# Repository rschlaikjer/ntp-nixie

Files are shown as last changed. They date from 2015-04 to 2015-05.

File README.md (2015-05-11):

# Nixie-NTP

### Nixie clock with NTP synchronisation

Like every amateur electrical engineer, I felt the need to make my own nixie
clock. However, I decided to add a bit of modern day tech and have the clock
set itself over NTP instead of requiring the user to manually adjust buttons.

The schematics provided detail the two boards - one control (arduino, ethernet)
and one display (shift registers, high voltage transistors).

## Partlist
#### (Digikey P/N in parens)

**Logic:**

- Atmega 328P (ATMEGA328-PU-ND / $3.01)
- Silvertel A9700 PoE module (N/A / $10)
- ENC28J60 ethernet PHY (ENC28J60-I/SO-ND / $2.83)
- RB1-125BHQ1A RJ45 jack with magnetics (N/A / $3.00)
- LM1117 3.3V regulator (LM1117T-3.3/NOPB-ND / $1.49)

**12-200V DC Boost:**
- 0.1uF 250V film cap (PCF1412CT-ND / $2.25)
- 4.7uF 450V alum cap (493-6196-1-ND / $1.51)
- MAX1771 DC-DC switching controller (MAX1771EPA+-ND / $7.23)
- 250V MOSFET (IRF644PBF-ND / $1.23)
- 100uF 20V tantalum cap (478-1746-1-ND / $2.52)
- 0.1uF 25V ceramic cap (490-1726-1-ND / $0.05)
- 10uF 25V tantalum cap (478-1762-1-ND / $1.02)
- 300V diode (ES2F-E3/52TGICT-ND / $0.40)
- 10k resistor (311-10.0KCRCT-ND / $0.02)
- 100uH inductor (M8603CT-ND / $0.81)
- 1.5M resistor (PT1.5MXCT-ND / $0.80)
- 0.05 ohm resistor (P50MCT-ND / $1.14)
- 5k trimmer pot (3214W-502ECT-ND / $3.18)

**Display Board**

- LS595 shift register with latch (296-1600-5-ND, $0.62)
- MPSA42 (or similar) high voltage transistors (MPSA42FS-ND, $0.22)
- Nixie tubes (Eagle footprint designed around the IN-14, YMMV)
- 1k resistors for regulating transistor base current
- 15k resistors for limiting nixie current

## Pretty pictures

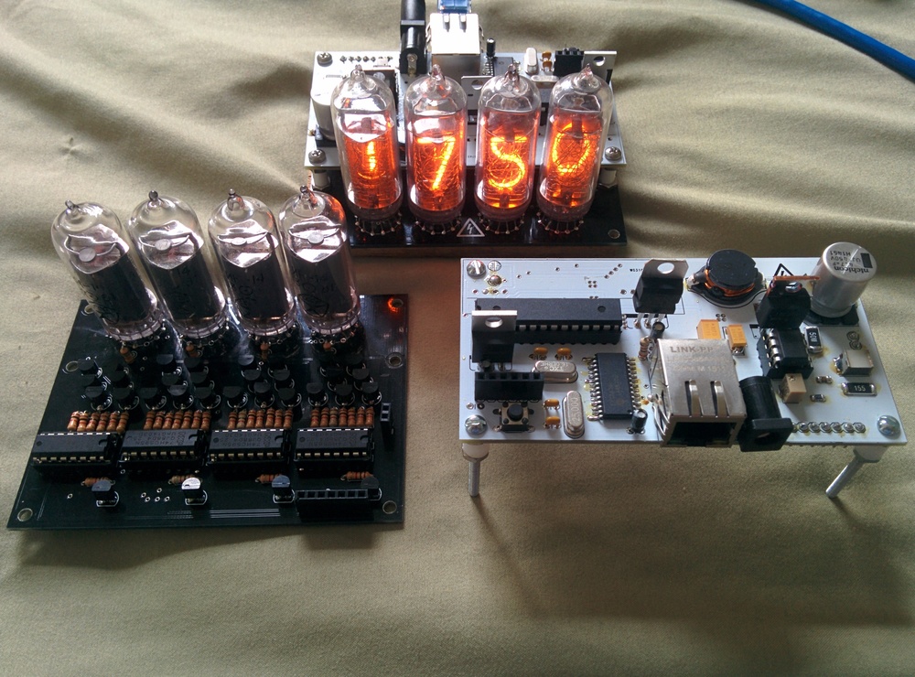
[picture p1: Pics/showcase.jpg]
Pretty It's alive

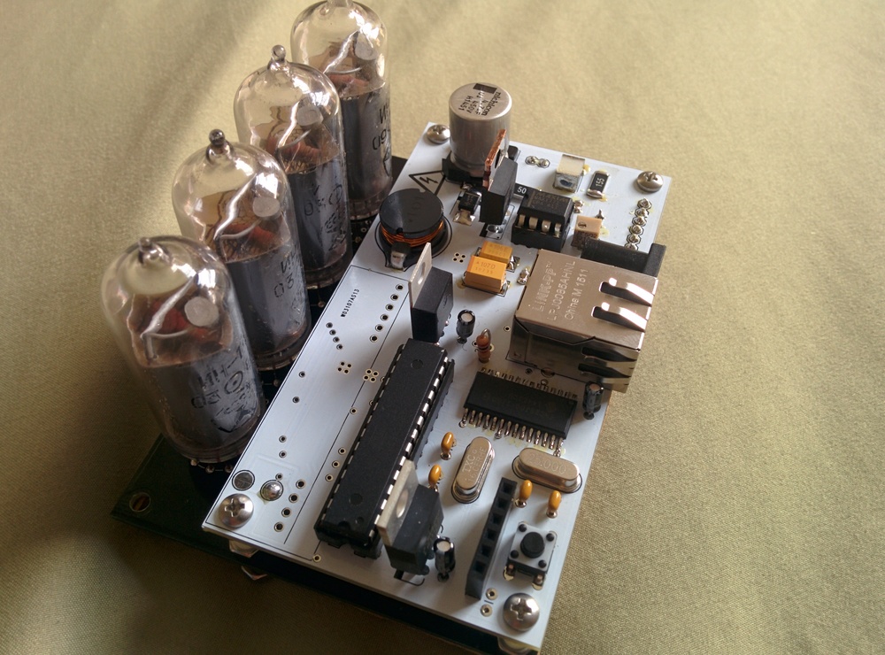
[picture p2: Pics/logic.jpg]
Logic Forward display

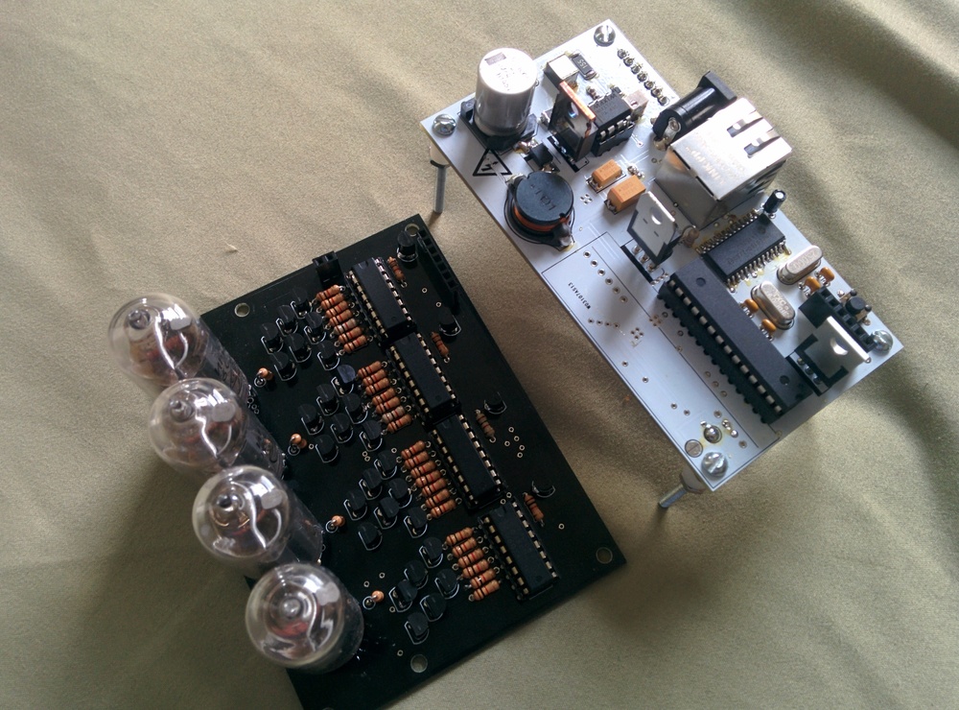
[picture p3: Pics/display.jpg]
Display Logic Display logic


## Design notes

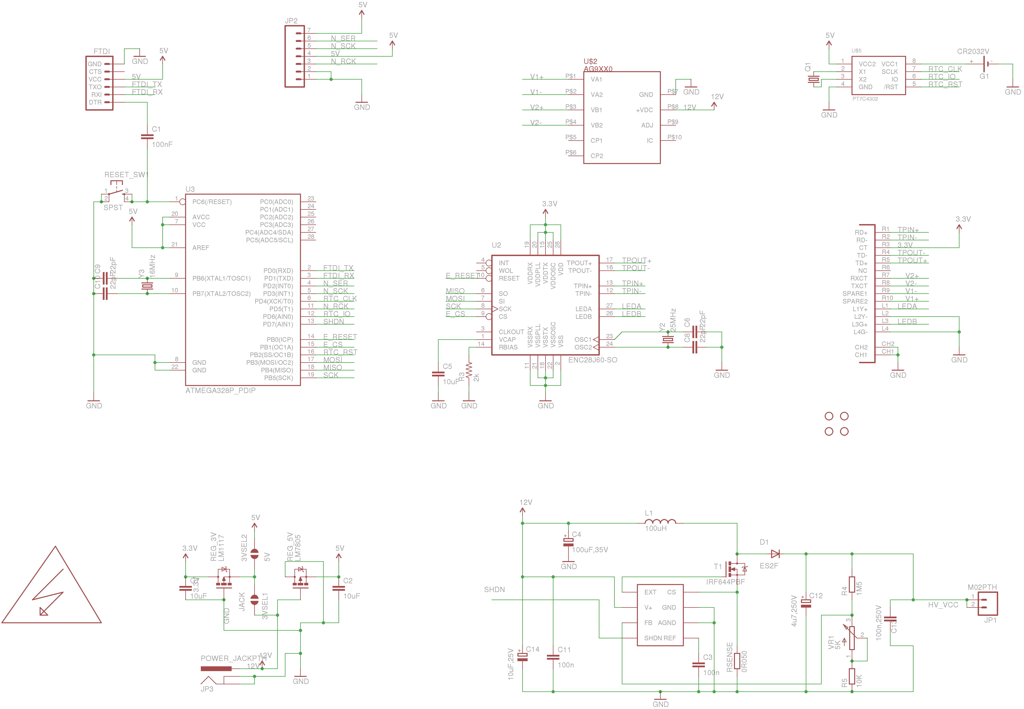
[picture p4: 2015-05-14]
Schematics/logic_schematic.png

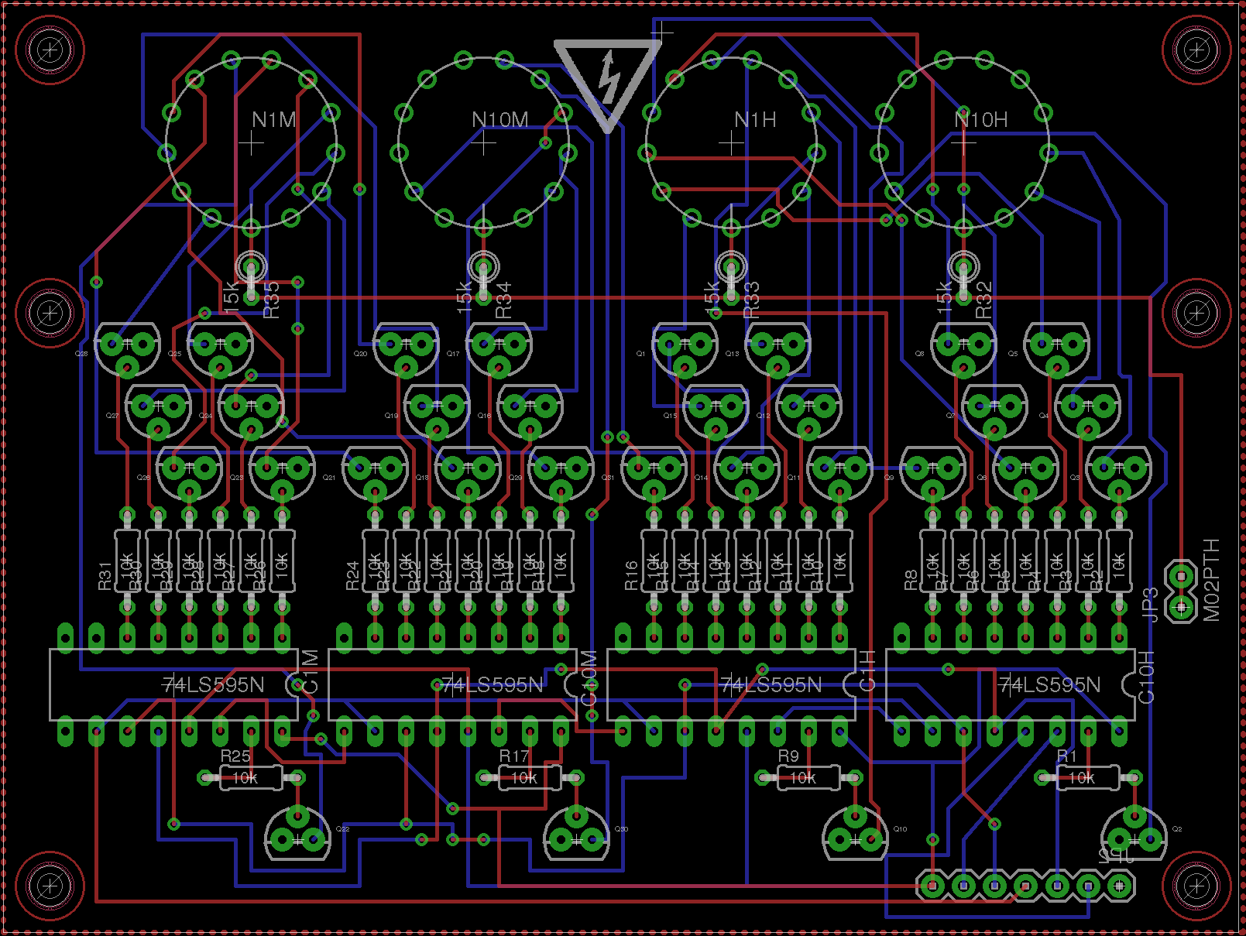
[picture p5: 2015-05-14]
Schematics/display_board.png

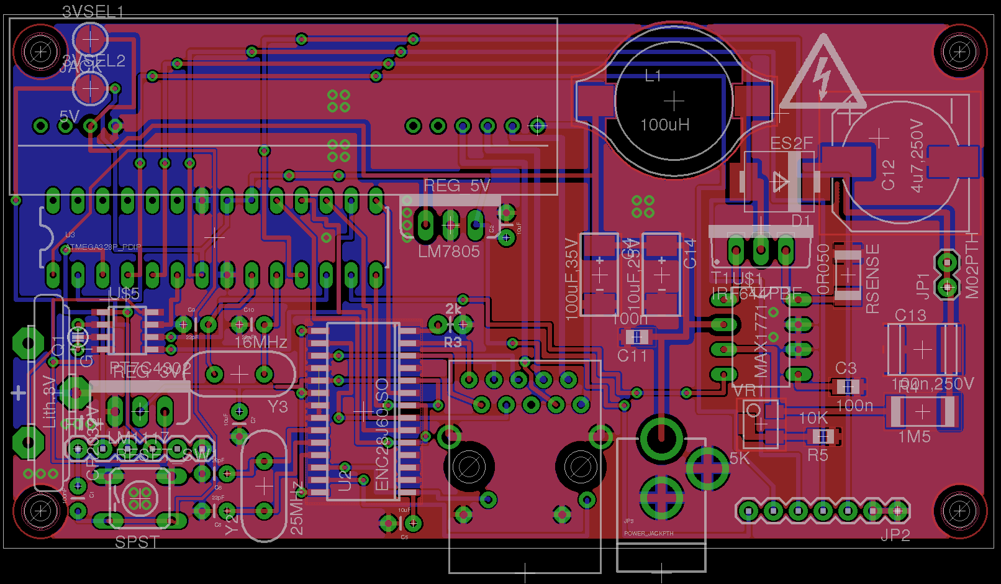
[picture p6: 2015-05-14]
Schematics/logic_board.png

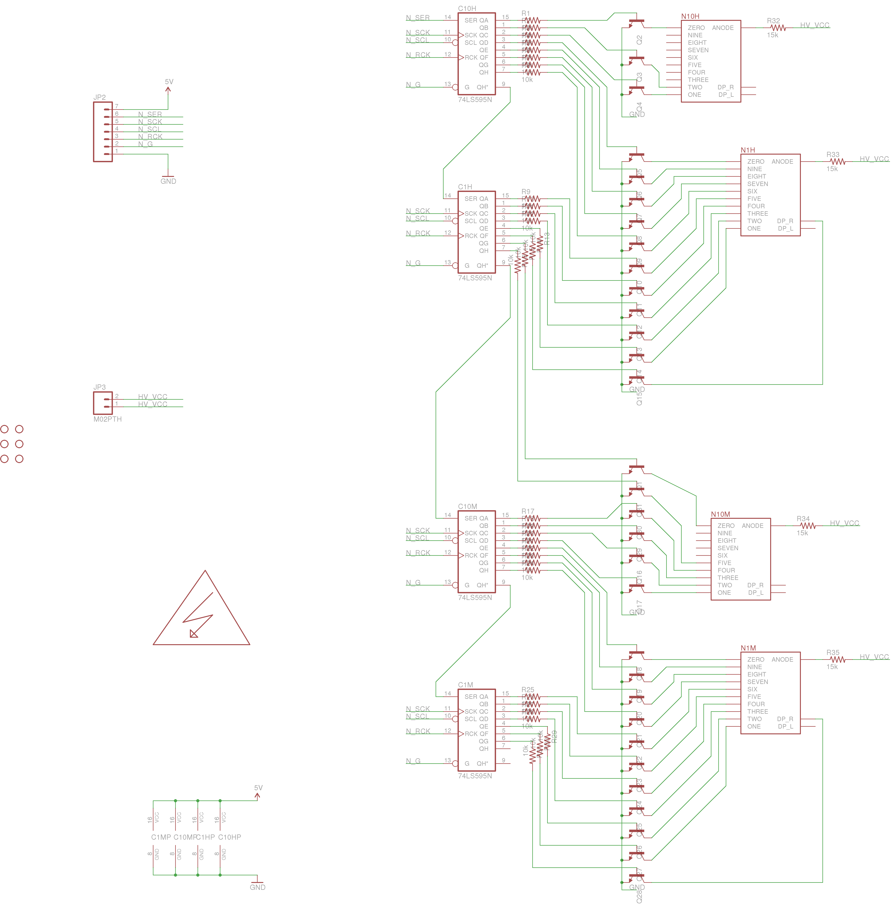
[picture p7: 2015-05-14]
Schematics/display_schematic.png

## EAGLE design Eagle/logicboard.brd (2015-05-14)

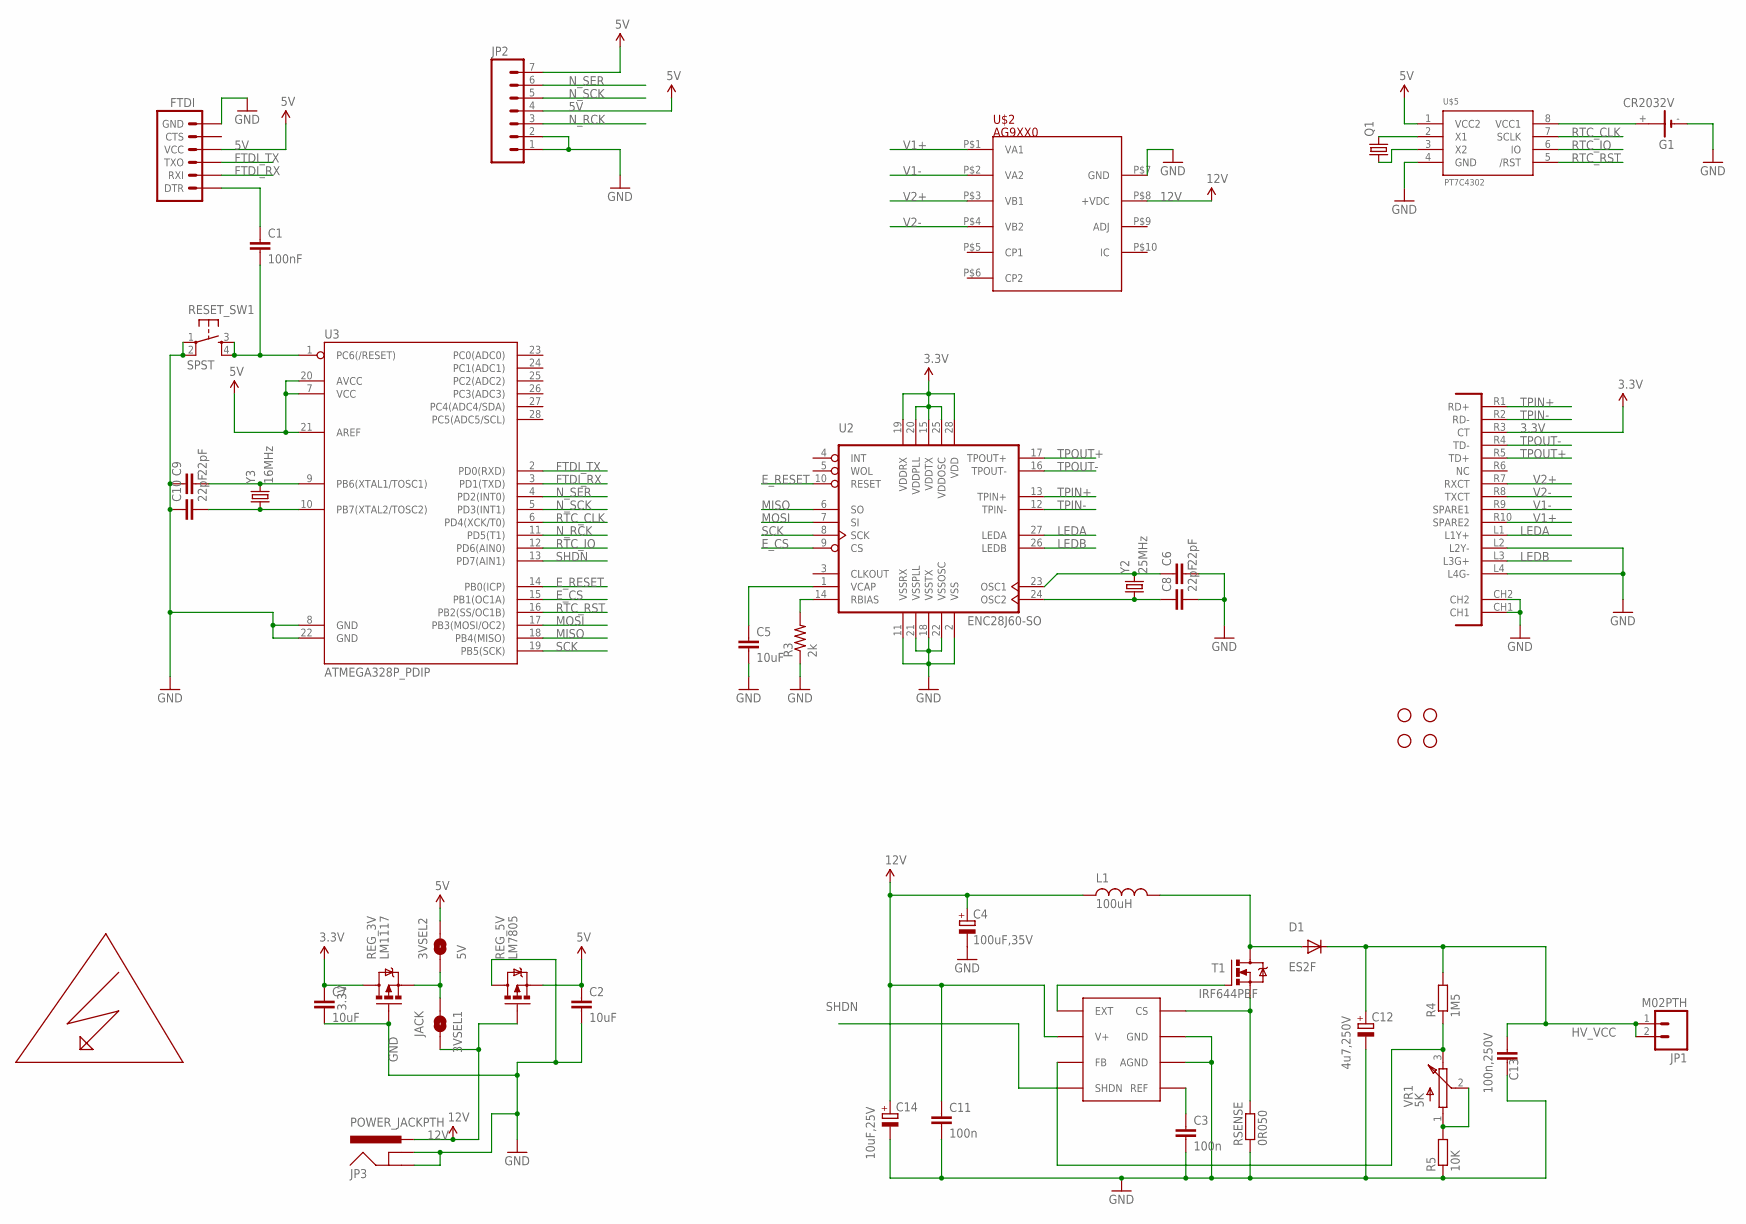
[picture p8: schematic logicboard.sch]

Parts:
3VSEL1: JACK; PAD-JUMPER-2-NO_YES_SILK_ROUND
3VSEL2: 5V; PAD-JUMPER-2-NO_YES_SILK_ROUND
C1: 100nF; CAP-PTH-SMALL
C2, C5, C7: 10uF; CAP-PTH-SMALL
C3, C11: 100n; C0805
C4: 100uF,35V; C-EIA-7343
C6, C8, C9, C10: 22pF; CAP-PTH-SMALL
C12: 4u7,250V; NICHICON-UJ-12
C13: 100n,250V; C2420
C14: 10uF,25V; C-EIA-7343
D1: ES2F; SMC
FTDI: ARDUINO_SERIAL_PROGRAMPTH; 1X06
G1: CR2032V
JP1: M02PTH; 1X02
JP2: M07; 1X07
JP3: POWER_JACKPTH; POWER_JACK_PTH
L1: 100uH; L-B82479
Q1: CRYSTALTC26V; TC26V
R3: 2k; AXIAL-0.1
R4: 1M5; R2512
R5: 10K; R0805
REG_3V: LM1117; TO220V
REG_5V: LM7805; TO220V
RESET_SW1: SPST; TAC-SWITCH-PTH
RSENSE: 0R050; R2010
STANDOFF1, STANDOFF2, STANDOFF3, STANDOFF4: STAND-OFF
T1: IRF644PBF; TO220BV
U2: ENC28J60-SO; SO28W
U3: ATMEGA328P_PDIP; DIL28-3
U$1: MAX1771; 8-DIP
U$2: AG9XX0; AG9000
U$3: POE-RJ45
U$4: HIGHVOLTAGE
U$5: PT7C4302; SO8
VR1: 5K; BOURNS-3214W
Y2: 25MHz; HC49US
Y3: 16MHz; HC49US

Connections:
3.3V: C7.1, REG_3V.2 (D), U2.15 (VDDTX), U2.19 (VDDRX), U2.20 (VDDPLL), U2.25 (VDDOSC), U2.28 (VDD), U$3.R3 (CT)
5V: 3VSEL2.2, C2.1, FTDI.4 (VCC), JP2.4, JP2.7, REG_5V.3 (S), U3.7 (VCC), U3.20 (AVCC), U3.21 (AREF), U$5.1 (VCC2)
12V: 3VSEL1.2, C4.+, C11.1, C14.+, JP3.PWR, L1.P$1 (1), REG_5V.1 (G), U$1.V+, U$2.P$8 (+VDC)
EXT: T1.G, U$1.EXT
E_CS: U2.9 (CS), U3.15 (PB1(OC1A))
E_RESET: U2.10 (RESET), U3.14 (PB0(ICP))
FTDI_RX: FTDI.2 (RXI), U3.3 (PD1(TXD))
FTDI_TX: FTDI.3 (TXO), U3.2 (PD0(RXD))
GND: C2.2, C3.2, C4.-, C5.2, C6.2, C7.2, C8.2, C9.1, C10.1, C11.2, C12.1 (-), C13.P$2 (2), C14.-, FTDI.6 (GND), G1.-, JP2.1, JP2.2, JP3.GND, JP3.GNDBREAK, R3.P$1 (1), R5.1, REG_3V.1 (G), REG_5V.2 (D), RESET_SW1.1, RESET_SW1.2, RSENSE.1, U2.2 (VSS), U2.11 (VSSRX), U2.18 (VSSTX), U2.21 (VSSPLL), U2.22 (VSSOSC), U3.8 (GND), U3.22 (GND), U$1.AGND, U$1.GND, U$2.P$7 (GND), U$3.CH1, U$3.CH2, U$3.L2 (L2Y-), U$3.L4 (L4G-), U$5.4 (GND)
HV_VCC: C12.2 (+), C13.P$1 (1), D1.C, JP1.1, JP1.2, R4.2
LEDA: U2.27 (LEDA), U$3.L1 (L1Y+)
LEDB: U2.26 (LEDB), U$3.L3 (L3G+)
MISO: U2.6 (SO), U3.18 (PB4(MISO))
MOSI: U2.7 (SI), U3.17 (PB3(MOSI/OC2))
unnamed: 3VSEL1.1, 3VSEL2.1, REG_3V.3 (S)
unnamed: G1.+, U$5.8 (VCC1)
unnamed: R3.P$2 (2), U2.14 (RBIAS)
unnamed: C5.1, U2.1 (VCAP)
unnamed: C6.1, U2.23 (OSC1), Y2.2
unnamed: C8.1, U2.24 (OSC2), Y2.1
unnamed: R5.2, VR1.1 (A), VR1.2 (W)
unnamed: R4.1, U$1.FB, VR1.3 (B)
unnamed: RSENSE.2, T1.S, U$1.CS
unnamed: C3.1, U$1.REF
unnamed: Q1.2, U$5.2 (X1)
unnamed: Q1.1, U$5.3 (X2)
unnamed: D1.A, L1.P$2 (2), T1.D
unnamed: C9.2, U3.9 (PB6(XTAL1/TOSC1)), Y3.2
unnamed: C10.2, U3.10 (PB7(XTAL2/TOSC2)), Y3.1
unnamed: C1.1, FTDI.1 (DTR)
N_RCK: JP2.3, U3.11 (PD5(T1))
N_SCK: JP2.5, U3.5 (PD3(INT1))
N_SER: JP2.6, U3.4 (PD2(INT0))
RESET: C1.2, RESET_SW1.3, RESET_SW1.4, U3.1 (PC6(/RESET))
RTC_CLK: U3.6 (PD4(XCK/T0)), U$5.7 (SCLK)
RTC_IO: U3.12 (PD6(AIN0)), U$5.6 (IO)
RTC_RST: U3.16 (PB2(SS/OC1B)), U$5.5 (/RST)
SCK: U2.8 (SCK), U3.19 (PB5(SCK))
SHDN: U3.13 (PD7(AIN1)), U$1.SHDN
TPIN+: U2.13 (TPIN+), U$3.R1 (RD+)
TPIN-: U2.12 (TPIN-), U$3.R2 (RD-)
TPOUT+: U2.17 (TPOUT+), U$3.R5 (TD+)
TPOUT-: U2.16 (TPOUT-), U$3.R4 (TD-)
V1+: U$2.P$1 (VA1), U$3.R10 (SPARE2)
V1-: U$2.P$2 (VA2), U$3.R9 (SPARE1)
V2+: U$2.P$3 (VB1), U$3.R7 (RXCT)
V2-: U$2.P$4 (VB2), U$3.R8 (TXCT)

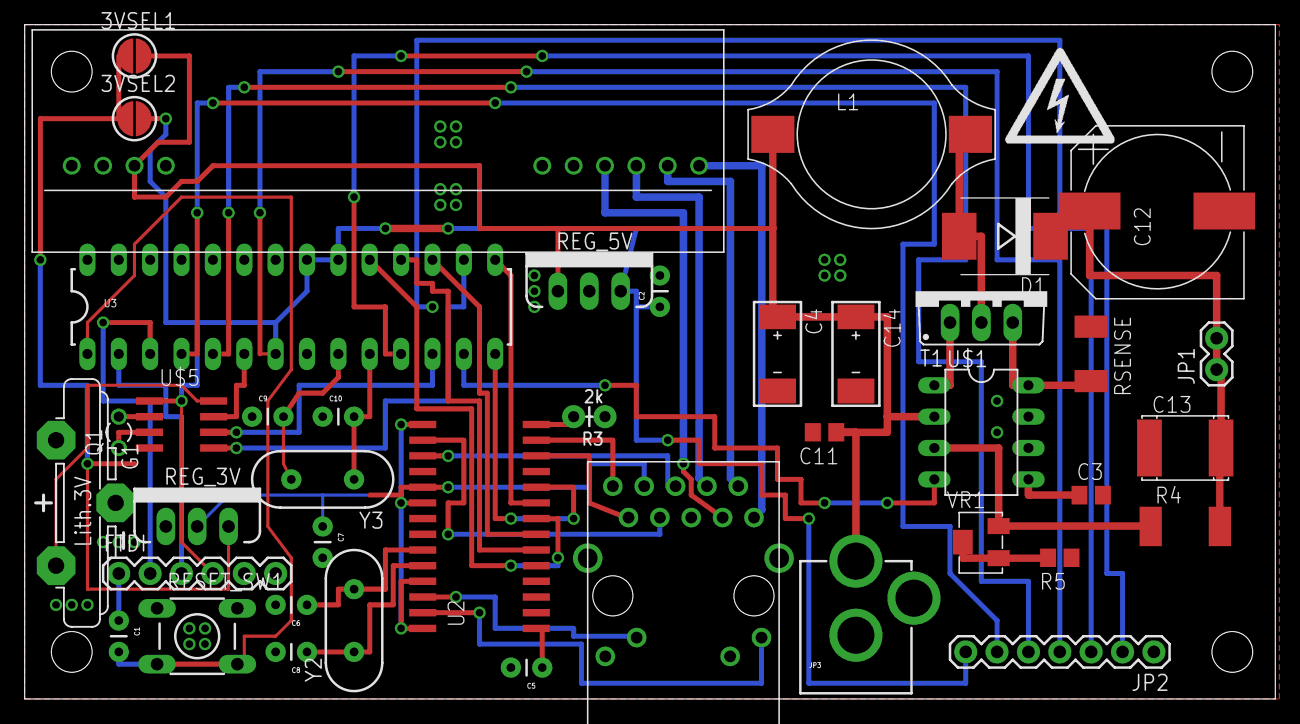
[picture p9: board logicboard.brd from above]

Board: 2 copper layers, 101.3 x 54.6 mm, 46 parts (0 on the bottom side), 47 nets.

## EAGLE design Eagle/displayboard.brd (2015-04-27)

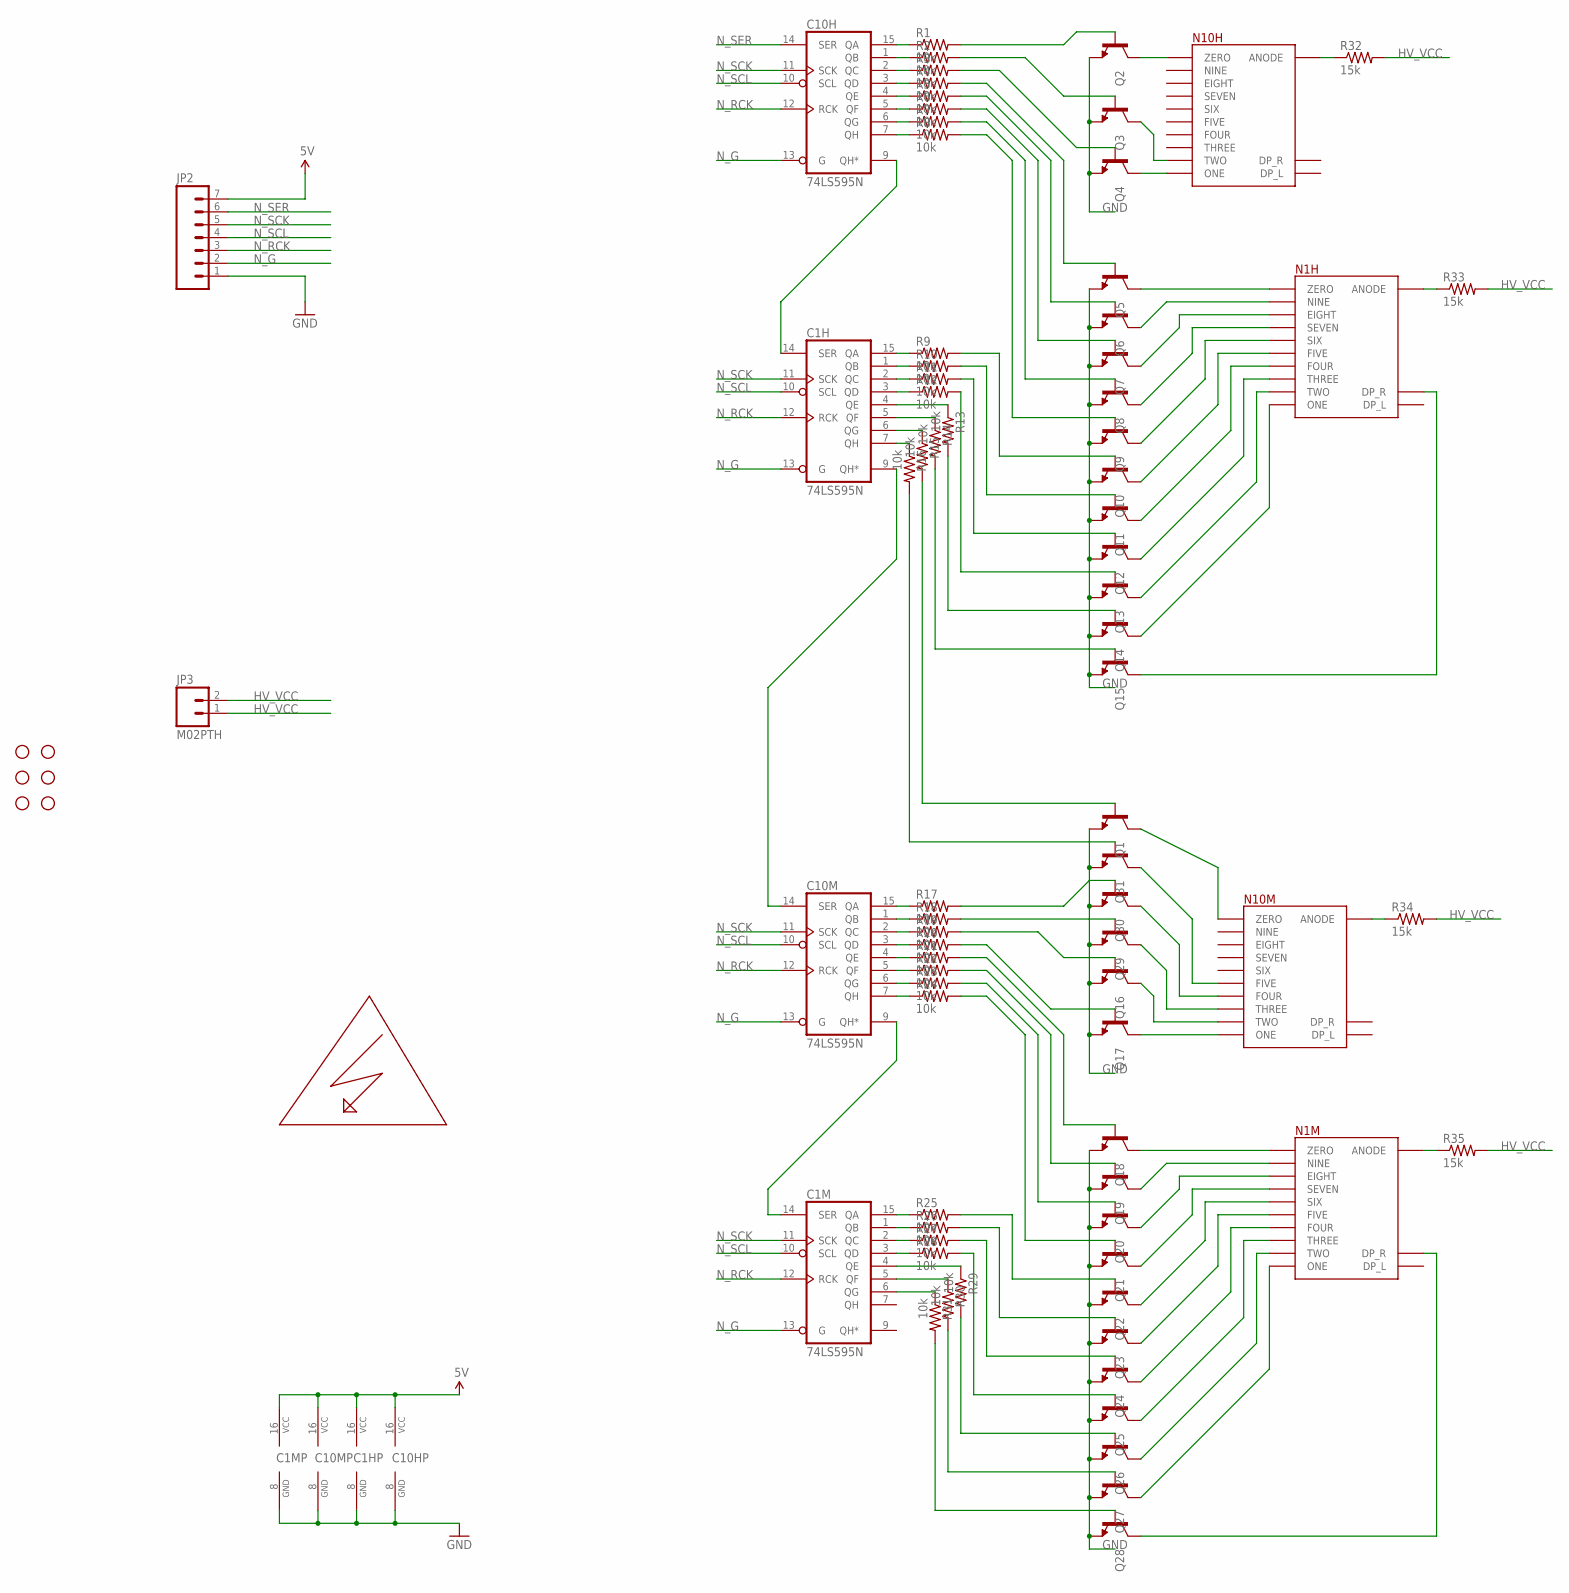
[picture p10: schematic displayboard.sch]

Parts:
C1H, C1M, C10H, C10M: 74LS595N; DIL16
JP2: M07; 1X07
JP3: M02PTH; 1X02
N1H, N1M, N10H, N10M: NIX13
Q1, Q2, Q3, Q4, Q5, Q6, Q7, Q8, Q9, Q10, Q11, Q12, Q13, Q14, Q15, Q16, Q17, Q18, Q19, Q20, Q21, Q22, Q23, Q24, Q25, Q26, Q27, Q28, Q29, Q30, Q31: TRANSISTOR_NPNTO92; TO-92
R1, R2, R3, R4, R5, R6, R7, R8, R9, R10, R11, R12, R13, R14, R15, R16, R17, R18, R19, R20, R21, R22, R23, R24, R25, R26, R27, R28, R29, R30, R31: 10k; 0204/7
R32, R33, R34, R35: 15k; 0207/2V
STANDOFF1, STANDOFF2, STANDOFF3, STANDOFF4, STANDOFF5, STANDOFF6: STAND-OFF
U$1: HIGHVOLTAGE

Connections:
5V: C1H.16 (VCC), C1M.16 (VCC), C10H.16 (VCC), C10M.16 (VCC), JP2.7
GND: C1H.8 (GND), C1M.8 (GND), C10H.8 (GND), C10M.8 (GND), JP2.1, Q1.1 (E), Q2.1 (E), Q3.1 (E), Q4.1 (E), Q5.1 (E), Q6.1 (E), Q7.1 (E), Q8.1 (E), Q9.1 (E), Q10.1 (E), Q11.1 (E), Q12.1 (E), Q13.1 (E), Q14.1 (E), Q15.1 (E), Q16.1 (E), Q17.1 (E), Q18.1 (E), Q19.1 (E), Q20.1 (E), Q21.1 (E), Q22.1 (E), Q23.1 (E), Q24.1 (E), Q25.1 (E), Q26.1 (E), Q27.1 (E), Q28.1 (E), Q29.1 (E), Q30.1 (E), Q31.1 (E)
HV_VCC: JP3.1, JP3.2, R32.2, R33.2, R34.2, R35.2
unnamed: N10H.ONE, Q4.3 (C)
unnamed: C10H.15 (QA), R1.1
unnamed: N10H.TWO, Q3.3 (C)
unnamed: N10H.ZERO, Q2.3 (C)
unnamed: N10M.THREE, Q29.3 (C)
unnamed: N1H.ONE, Q14.3 (C)
unnamed: N1H.TWO, Q13.3 (C)
unnamed: N1H.THREE, Q12.3 (C)
unnamed: N1H.FOUR, Q11.3 (C)
unnamed: N1H.FIVE, Q10.3 (C)
unnamed: N1H.SIX, Q9.3 (C)
unnamed: N1H.SEVEN, Q8.3 (C)
unnamed: N1H.EIGHT, Q7.3 (C)
unnamed: N1H.NINE, Q6.3 (C)
unnamed: N1H.ZERO, Q5.3 (C)
unnamed: N10M.FOUR, Q30.3 (C)
unnamed: N1H.DP_R, Q15.3 (C)
unnamed: Q2.2 (B), R1.2
unnamed: Q3.2 (B), R2.2
unnamed: C10H.1 (QB), R2.1
unnamed: C10H.2 (QC), R3.1
unnamed: Q4.2 (B), R3.2
unnamed: Q5.2 (B), R4.2
unnamed: Q6.2 (B), R5.2
unnamed: Q7.2 (B), R6.2
unnamed: Q8.2 (B), R7.2
unnamed: Q9.2 (B), R8.2
unnamed: Q10.2 (B), R9.2
unnamed: Q11.2 (B), R10.2
unnamed: Q12.2 (B), R11.2
unnamed: Q13.2 (B), R12.2
unnamed: Q14.2 (B), R13.2
unnamed: Q15.2 (B), R14.2
unnamed: N10M.ONE, Q17.3 (C)
unnamed: N10M.FIVE, Q31.3 (C)
unnamed: Q1.2 (B), R15.2
unnamed: N1M.ONE, Q27.3 (C)
unnamed: N1M.TWO, Q26.3 (C)
unnamed: N1M.THREE, Q25.3 (C)
unnamed: N1M.FOUR, Q24.3 (C)
unnamed: N1M.FIVE, Q23.3 (C)
unnamed: N1M.SIX, Q22.3 (C)
unnamed: N1M.SEVEN, Q21.3 (C)
unnamed: N1M.EIGHT, Q20.3 (C)
unnamed: N1M.NINE, Q19.3 (C)
unnamed: N1M.ZERO, Q18.3 (C)
unnamed: N10M.TWO, Q16.3 (C)
unnamed: N10M.ZERO, Q1.3 (C)
unnamed: N1M.DP_R, Q28.3 (C)
unnamed: Q30.2 (B), R17.2
unnamed: C10M.15 (QA), R17.1
unnamed: Q29.2 (B), R18.2
unnamed: C10H.3 (QD), R4.1
unnamed: C10H.4 (QE), R5.1
unnamed: C10H.5 (QF), R6.1
unnamed: C10H.6 (QG), R7.1
unnamed: Q22.2 (B), R25.2
unnamed: Q23.2 (B), R26.2
unnamed: Q24.2 (B), R27.2
unnamed: Q25.2 (B), R28.2
unnamed: Q26.2 (B), R29.2
unnamed: Q27.2 (B), R30.2
unnamed: Q28.2 (B), R31.2
unnamed: C1H.14 (SER), C10H.9 (QH*)
unnamed: C1H.9 (QH*), C10M.14 (SER)
unnamed: C1M.14 (SER), C10M.9 (QH*)
unnamed: Q31.2 (B), R16.2
unnamed: Q17.2 (B), R20.2
unnamed: Q20.2 (B), R23.2
unnamed: Q18.2 (B), R21.2
unnamed: Q19.2 (B), R22.2
unnamed: Q21.2 (B), R24.2
unnamed: C10H.7 (QH), R8.1
unnamed: C1H.15 (QA), R9.1
unnamed: C1H.2 (QC), R11.1
unnamed: C1H.1 (QB), R10.1
unnamed: C1H.3 (QD), R12.1
unnamed: C1H.4 (QE), R13.1
unnamed: C1H.5 (QF), R14.1
unnamed: C1H.6 (QG), R15.1
unnamed: C1H.7 (QH), R16.1
unnamed: C10M.1 (QB), R18.1
unnamed: C10M.2 (QC), R19.1
unnamed: C10M.3 (QD), R20.1
unnamed: C10M.4 (QE), R21.1
unnamed: C10M.5 (QF), R22.1
unnamed: C10M.6 (QG), R23.1
unnamed: C10M.7 (QH), R24.1
unnamed: Q16.2 (B), R19.2
unnamed: C1M.15 (QA), R25.1
unnamed: C1M.1 (QB), R26.1
unnamed: C1M.2 (QC), R27.1
unnamed: C1M.3 (QD), R28.1
unnamed: C1M.4 (QE), R29.1
unnamed: C1M.5 (QF), R30.1
unnamed: C1M.6 (QG), R31.1
unnamed: N10H.ANODE, R32.1
unnamed: N1M.ANODE, R35.1
unnamed: N10M.ANODE, R34.1
unnamed: N1H.ANODE, R33.1
N_G: C1H.13 (G), C1M.13 (G), C10H.13 (G), C10M.13 (G), JP2.2
N_RCK: C1H.12 (RCK), C1M.12 (RCK), C10H.12 (RCK), C10M.12 (RCK), JP2.3
N_SCK: C1H.11 (SCK), C1M.11 (SCK), C10H.11 (SCK), C10M.11 (SCK), JP2.5
N_SCL: C1H.10 (SCL), C1M.10 (SCL), C10H.10 (SCL), C10M.10 (SCL), JP2.4
N_SER: C10H.14 (SER), JP2.6

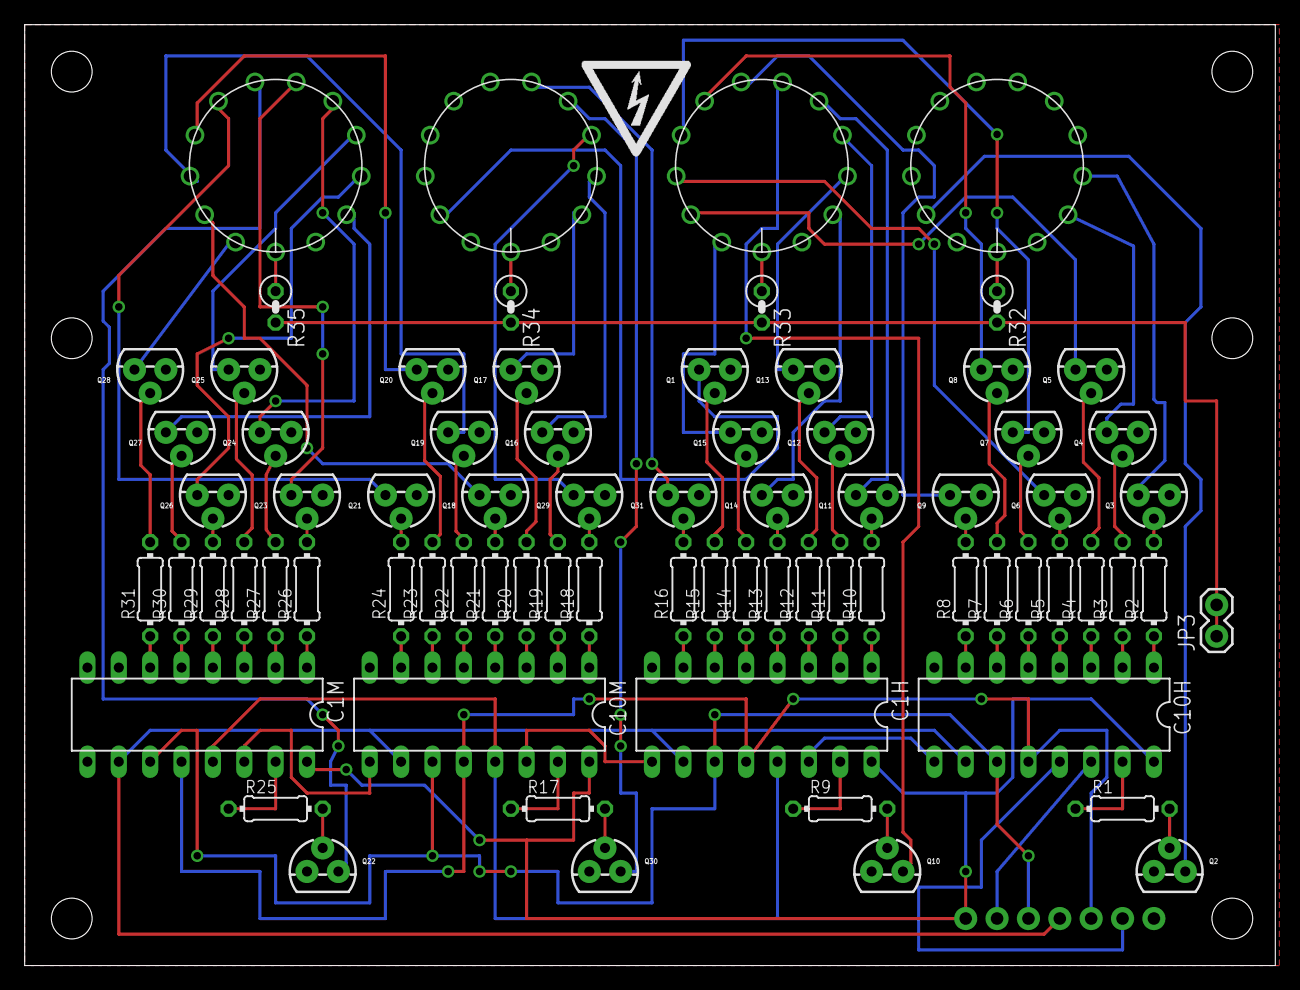
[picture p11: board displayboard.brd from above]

Board: 2 copper layers, 101.3 x 76.2 mm, 83 parts (1 on the bottom side), 108 nets.

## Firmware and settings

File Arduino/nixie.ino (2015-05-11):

#include <EtherCard.h>
#include <Time.h>
#include <Timezone.h>

#define N_SER 2
#define N_SCK 3
#define N_RCK 5
#define N_SCL 4
#define N_G   6

#define HV_SHDN 7

// Timezone: US East
TimeChangeRule usEDT = {"EDT", Second, Sun, Mar, 2, -240};  //UTC - 4 hours
TimeChangeRule usEST = {"EST", First, Sun, Nov, 2, -300};   //UTC - 5 hours
Timezone usEastern(usEDT, usEST);

// Ethernet
byte mac[] = {0xDE, 0xAD, 0xBE, 0xEF, 0xBA, 0xB1};
#define BUFFER_SIZE 800
byte Ethernet::buffer[BUFFER_SIZE];

// NTP
const char ntp_servname[] PROGMEM = "0.pool.ntp.org";
//uint8_t ntp_srv[] = {129,  6,   15,   29};

unsigned long millis_offset = 0;
uint8_t clientPort = 123;

// Tick scheduling
unsigned long update_interval = 1000L * 60L * 60L; // One hour
uint32_t lastUpdate = 0;
unsigned long update_display_interval = 1000L * 5L; // 5 seconds
uint32_t lastDisplayUpdate = 0;
uint32_t timeLong;

// Function prototypes
void write_595_time(uint8_t hours, uint8_t minutes, bool dp);

unsigned long getNtpTime(bool idle_anim) {
    unsigned long timeFromNTP;
    const unsigned long seventy_years = 2208988800UL;

    if (!ether.dnsLookup(ntp_servname)){
        Serial.println("DNS lookup failed");
        return 0;
    }

    ether.ntpRequest(ether.hisip, clientPort);

    int hours = 0;
    int minutes = 0;
    unsigned long idle_tick = 0;
    while(true){
        if (idle_anim && (millis() - idle_tick > 250)){
            idle_tick = millis();
            write_595_time(hours, minutes, false);
            hours = (hours + 1) % 24;
            minutes = (minutes + 1) % 60;
        }
        word length = ether.packetReceive();
        ether.packetLoop(length);
        if(length > 0 && ether.ntpProcessAnswer(&timeFromNTP, clientPort)) {
            return usEastern.toLocal(timeFromNTP - seventy_years);
        }
    }
    return 0;
}


void write_595_time(uint8_t hours, uint8_t minutes, bool dp){
    /*
       Shift register bit meanings:

    0, 1   : 10H Zero
    0, 2   : 10H Two
    0, 4   : 10H One
    0, 8   :  1H Zero
    0, 16  :  1H Nine
    0, 32  :  1H Eight
    0, 64  :  1H Seven
    0, 128 :  1H Six

    1, 1   :  1H Five
    1, 2   :  1H Four
    1, 4   :  1H Three
    1, 8   :  1H Two
    1, 16  :  1H One
    1, 32  :  1H Decimal
    1, 64  : 10M Zero
    1, 128 : 10M Five

    2, 1   : 10M Four
    2, 2   : 10M Three
    2, 4   : 10M Two
    2, 8   : 10M One
    2, 16  :  1M Zero
    2, 32  :  1M Nine
    2, 64  :  1M Eight
    2, 128 :  1M Seven

    2, 1   :  1M Six
    2, 2   :  1M Five
    2, 4   :  1M Four
    2, 8   :  1M Three
    2, 16  :  1M Two
    2, 32  :  1M One
    2, 64  :  1M Decimal
    2, 128 :  NC
    */


    uint8_t out[] = { 0, 0, 0, 0 };

    // Hour tens
    switch (hours / 10){
        case 0: out[0] |= 0x01; break;
        case 1: out[0] |= 0x04; break;
        case 2: out[0] |= 0x02; break;
    }

    // Hour ones
    switch (hours % 10){
        case 0: out[0] |= 0x08; break;
        case 9: out[0] |= 0x10; break;
        case 8: out[0] |= 0x20; break;
        case 7: out[0] |= 0x40; break;
        case 6: out[0] |= 0x80; break;
        case 5: out[1] |= 0x01; break;
        case 4: out[1] |= 0x02; break;
        case 3: out[1] |= 0x04; break;
        case 2: out[1] |= 0x08; break;
        case 1: out[1] |= 0x10; break;
    }

    // Minute tens
    switch (minutes / 10){
        case 0: out[1] |= 0x40; break;
        case 5: out[1] |= 0x80; break;
        case 4: out[2] |= 0x01; break;
        case 3: out[2] |= 0x02; break;
        case 2: out[2] |= 0x04; break;
        case 1: out[2] |= 0x08; break;
    }

    // Minute ones
    switch (minutes % 10){
        case 0: out[2] |= 0x10; break;
        case 9: out[2] |= 0x20; break;
        case 8: out[2] |= 0x40; break;
        case 7: out[2] |= 0x80; break;
        case 6: out[3] |= 0x01; break;
        case 5: out[3] |= 0x02; break;
        case 4: out[3] |= 0x04; break;
        case 3: out[3] |= 0x08; break;
        case 2: out[3] |= 0x10; break;
        case 1: out[3] |= 0x20; break;
    }

    if (dp){
        out[1] |= 0x20;
        out[3] |= 0x40;
    }

    Serial.print("Bit data: ");
    Serial.print(out[0], BIN);
    Serial.print(" ");
    Serial.print(out[1], BIN);
    Serial.print(" ");
    Serial.print(out[2], BIN);
    Serial.print(" ");
    Serial.println(out[3], BIN);

    // Output the data to the shift regs
    digitalWrite(N_RCK, LOW);
    shiftOut(N_SER, N_SCK, MSBFIRST, out[3]);
    shiftOut(N_SER, N_SCK, MSBFIRST, out[2]);
    shiftOut(N_SER, N_SCK, MSBFIRST, out[1]);
    shiftOut(N_SER, N_SCK, MSBFIRST, out[0]);
    digitalWrite(N_RCK, HIGH);
}

void print_time(){
    unsigned long time;
    time = (millis()/1000) + millis_offset;
    time = time % (60L * 60L * 24L);
    unsigned hours = (time / 60 / 60) % 24;
    unsigned minutes = (time / 60) % 60;
    unsigned seconds = time % 60;
    Serial.print(hours);
    Serial.print(":");
    Serial.print(minutes);
    Serial.print(".");
    Serial.println(seconds);
}

void update_offset(bool idle_anim){
    unsigned long time = getNtpTime(idle_anim);
    if (time){
        millis_offset = (time - (millis()/1000));
    }
}

bool dp = true;
void loop(){
    ether.packetLoop(ether.packetReceive());

    // Update the NTP offset each hour
    if(lastUpdate +  update_interval < millis()) {
        lastUpdate = millis();
        update_offset(false);
    }

    // Update the readout every ten seconds
    if (lastDisplayUpdate + update_display_interval < millis()){
        lastDisplayUpdate = millis();

        // Get the hours & minutes
        unsigned long time;
        time = (millis()/1000) + millis_offset;
        time = time % (60L * 60L * 24L);
        uint8_t hours = (time / 60 / 60) % 24;
        uint8_t minutes = (time / 60) % 60;

        // Print the time
        print_time();
        write_595_time(hours, minutes, dp);
        dp = !dp;
    }
}

void setup(){
    Serial.begin(19200);

    // HV Control pin, start with shutdown high
    pinMode(HV_SHDN, OUTPUT);
    digitalWrite(HV_SHDN, HIGH);

    // Shift register setup
    pinMode(N_SER, OUTPUT);
    pinMode(N_SCK, OUTPUT);
    pinMode(N_SCL, OUTPUT);
    pinMode(N_RCK, OUTPUT);
    pinMode(N_G, OUTPUT);
    digitalWrite(N_SCL, HIGH);
    digitalWrite(N_G, LOW);


    // Ethernet
    if (ether.begin(sizeof Ethernet::buffer, mac, 9) == 0){
        Serial.println("Couldn't init eth");
        while (1);
    }

    Serial.print("DHCP...");
    //ether.staticSetup(myip, gwip, gwip);
    //static byte dnsip[] = {8,8,8,8};
    //ether.copyIp(ether.dnsip, dnsip);
    if (!ether.dhcpSetup()){
        Serial.println(" failed.");
        while(1);
    }
    Serial.println("done.");

    lastUpdate = millis();
    Serial.println("Setup done");

    // Enable the HV system
    digitalWrite(HV_SHDN, LOW);

    // Get an initial NTP offset
    update_offset(true);
}

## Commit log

2015-04-04 Add v0 eagle files
    [displayboard.brd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]
2015-04-04 Add arduino code
2015-04-27 Add controls for onboard 200V PSU
2015-04-27 Update schematic to include on-board 200V psu
    [displayboard.brd, displayboard.sch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]
2015-05-11 Ensure latest eagle
    [logicboard.brd, logicboard.sch]
2015-05-14 Update schematics, finish RTC addition
    [logicboard.brd, logicboard.sch]
2015-05-14 Break out schematics

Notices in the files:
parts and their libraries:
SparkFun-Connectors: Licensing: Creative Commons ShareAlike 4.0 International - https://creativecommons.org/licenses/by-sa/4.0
